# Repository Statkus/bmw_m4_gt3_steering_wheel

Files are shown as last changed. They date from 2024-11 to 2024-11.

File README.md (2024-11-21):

# BMW M4 GT3 steering wheel

This project is a rough replica of the BMW M4 GT3 wheel, entirely printed in 3D with plastic filament.

## Bill of materials

- PLA or any other filament that you like
- screws:
  - 4 x DIN 912 M2 10mm
  - 1 x DIN 912 M2.5 10mm
  - 28 x DIN 912 M3 6mm
  - 6 x DIN 912 M3 16mm
  - 4 x DIN 912 M3 25mm
  - 6 x DIN 912 M5 55mm
  - 8 x DIN 912 M6 22mm
- nuts:
  - 4 x M2
  - 1 x M2.5
  - 10 x M3
  - 6 x M5
  - 8 x M6
- 28 x M3 inserts OD 5mm length 5mm
- 4 x 12x3mm magnets
- tennis handle grip or similar material for the handles
- 1 x WeAct Black Pill V3.0 (https://stm32-base.org/boards/STM32F401CEU6-WeAct-Black-Pill-V3.0) or any STM32F411CEU6 based board with same form factor
- 12 x pins from deutsch connectors 0460-202-20141
- 1 x 12 pins JST PH male connector
- 1 x 12 pins JST PH female connector
- 5 x EC11 encoders with 15mm plum handle with or without push buttons
- 14 x B3F-4055 tactile switches
- 14 x 10mm caps for B3F-4055 tactile switchs
- 2 x DM1-01P-30-3 switches
- wires to link everything

## Source code

### Usage

STM32CubeMX is used to generate STM32 library source files.

Source code can be build with the command:
```
make all
```

And you can flash the program with:
```
make flash
```

STM32CubeMX generates file in DOS format, to convert files to UNIX format use:
```
make format
```

### Fanatec SPI protocol

The SPI protocol used between the fanatec wheel and wheel base as already been retro engineered. Reference of this protocol can be found on the following GitHub repositories:
- https://github.com/Alexbox364/F_Interface_AL
- https://github.com/darknao/btClubSportWheel
- https://github.com/lshachar/Arduino_Fanatec_Wheel

The pinout of the QR pins can already be found on those repositories.

## 3D files

3D_files/Pin_holder_FINAL.stl and 3D_files/Pin_locker_FINAL.stl have been designed by Alexbox364 and are available on Thingiverse: https://www.thingiverse.com/thing:6271297.

The other parts are designed with FreeCAD.

## TODO

- Add clutch paddles

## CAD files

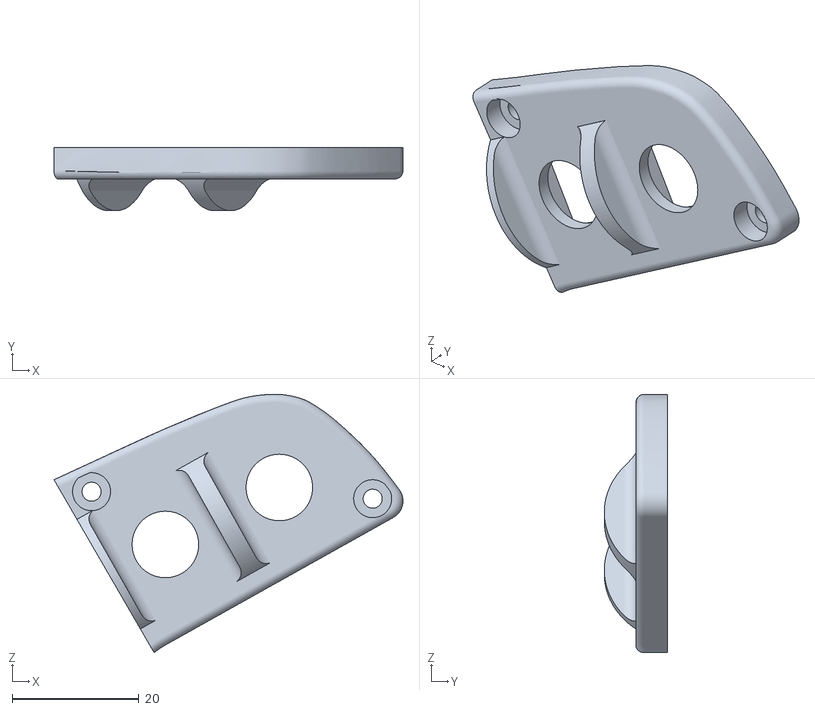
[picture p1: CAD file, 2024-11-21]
3D_files/wheel_tip_front_right.stl
55.1 x 10.0 x 40.8

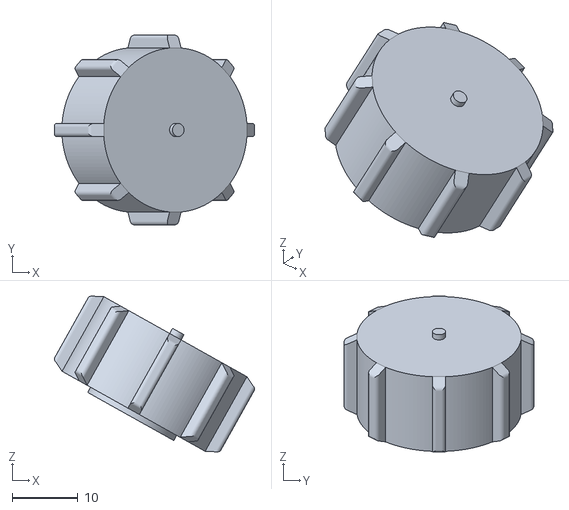
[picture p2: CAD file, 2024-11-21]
3D_files/handle_encoder_cap.stl
30.4 x 28.9 x 23.7

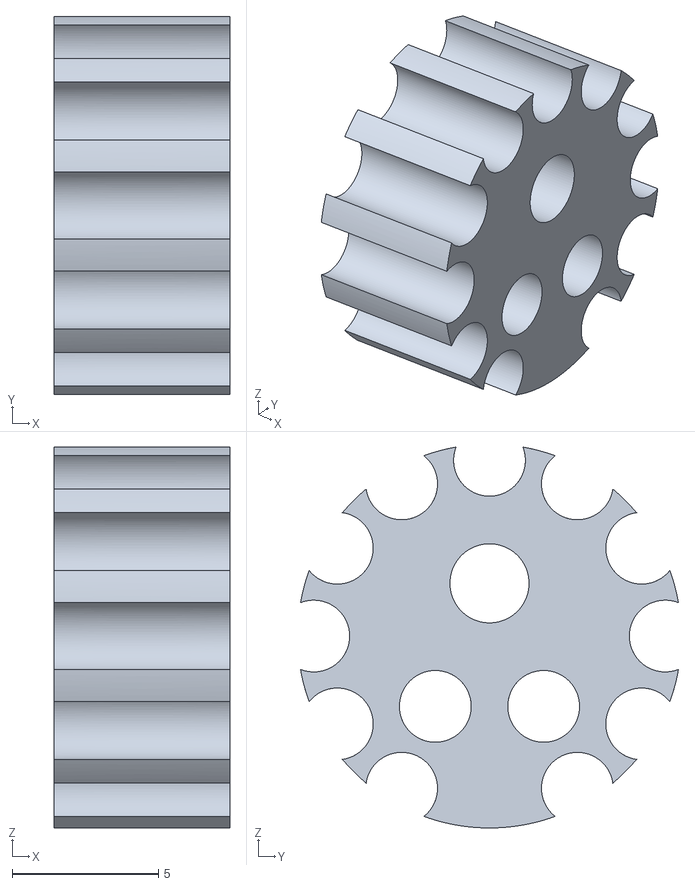
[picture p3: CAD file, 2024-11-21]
3D_files/Pin_locker_FINAL.stl
6.00 x 12.9 x 13.0

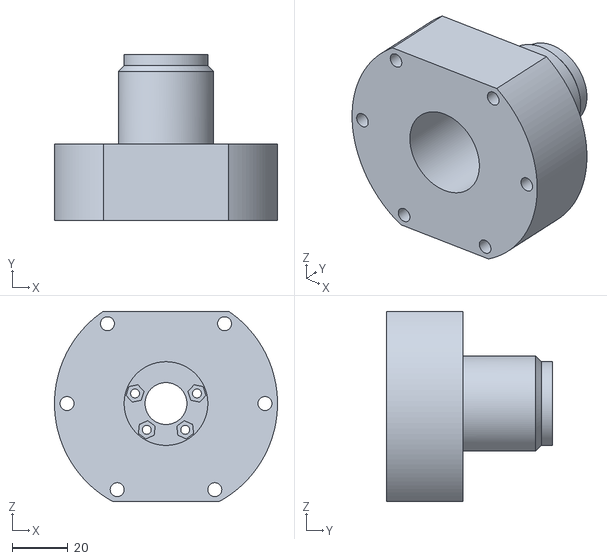
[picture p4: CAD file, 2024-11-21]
3D_files/QR_adapter.stl
80.0 x 59.5 x 68.3

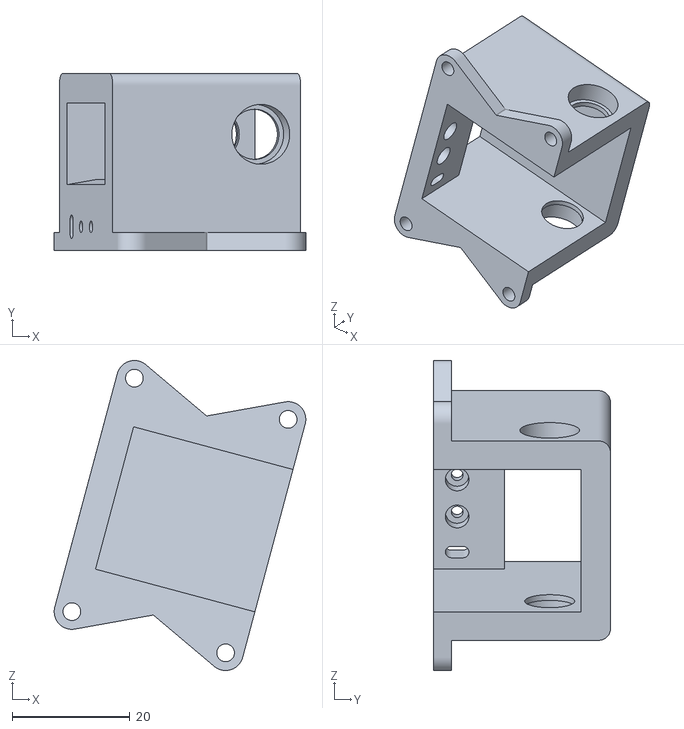
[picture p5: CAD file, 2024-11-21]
3D_files/shifter_core.stl
42.7 x 30.0 x 52.6

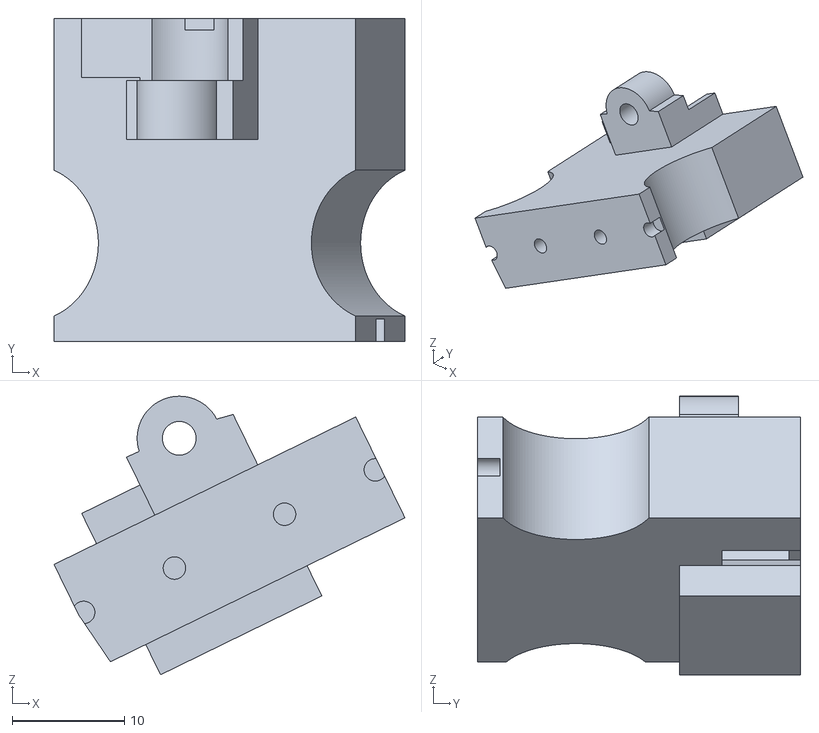
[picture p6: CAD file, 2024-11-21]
3D_files/wheel_tip_internal_right.stl
31.3 x 28.8 x 24.8

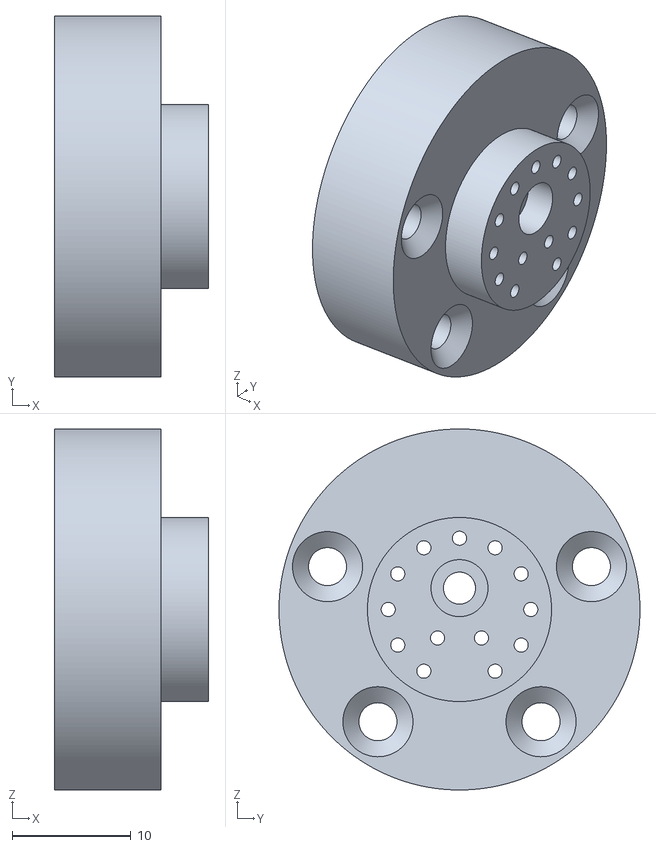
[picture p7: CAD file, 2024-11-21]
3D_files/Pin_holder_FINAL.stl
13.0 x 30.4 x 30.4

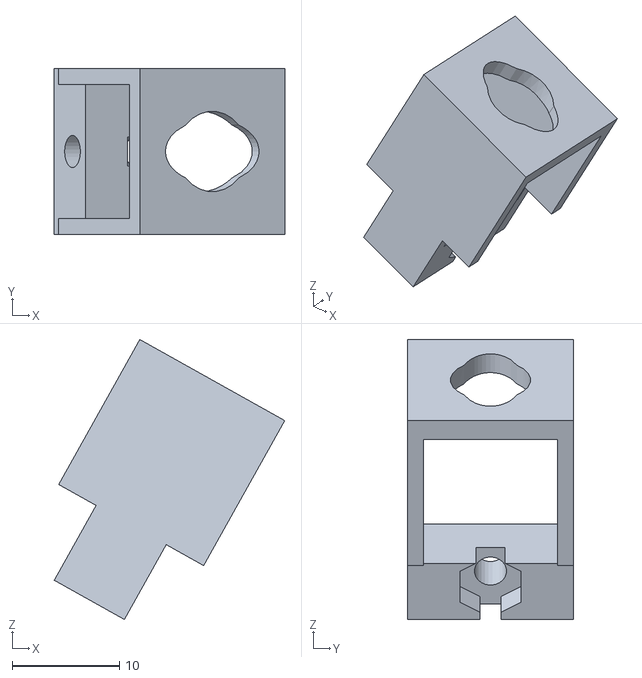
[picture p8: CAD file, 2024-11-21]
3D_files/handle_encoder.stl
21.5 x 15.5 x 26.1

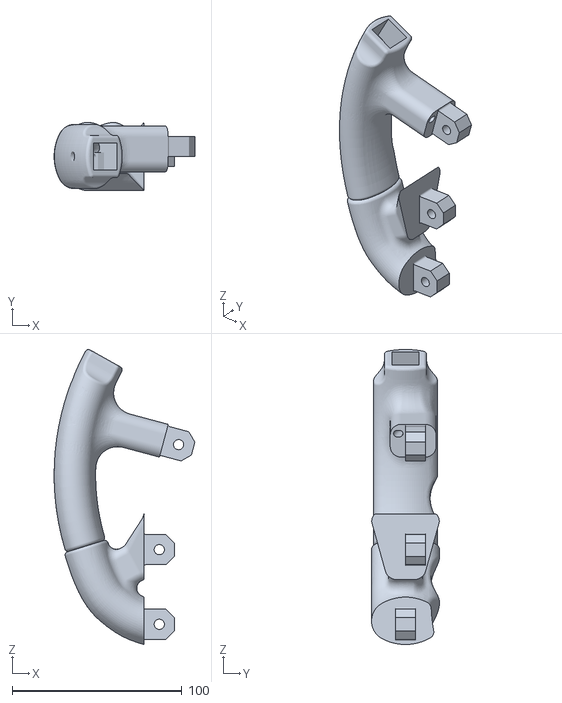
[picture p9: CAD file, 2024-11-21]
3D_files/handle_left.stl
83.0 x 40.0 x 173.9

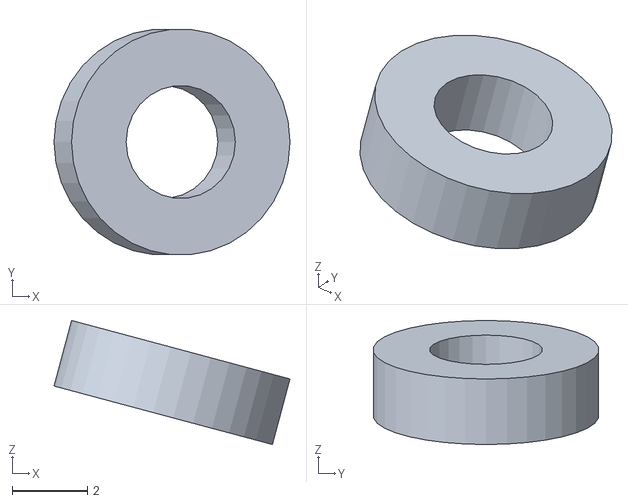
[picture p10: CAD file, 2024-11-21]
3D_files/shifter_bearing_spacer.stl
6.26 x 5.97 x 3.29

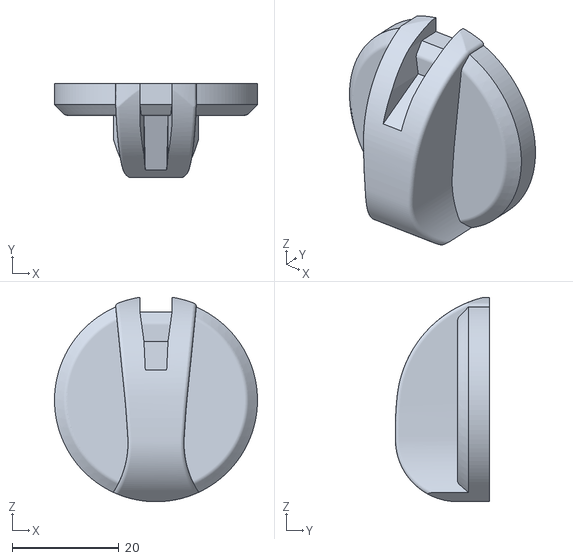
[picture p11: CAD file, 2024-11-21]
3D_files/core_encoder_cap.stl
38.0 x 17.7 x 38.3

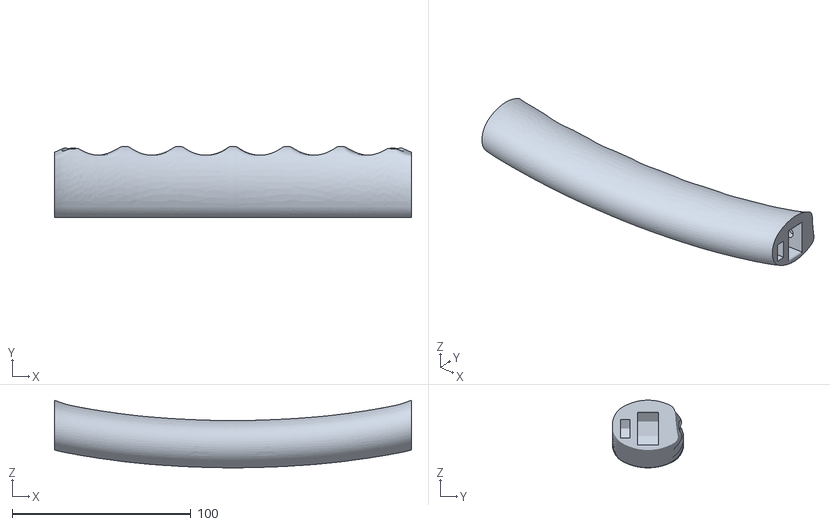
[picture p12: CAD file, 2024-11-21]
3D_files/bottom.stl
200.0 x 40.0 x 37.9

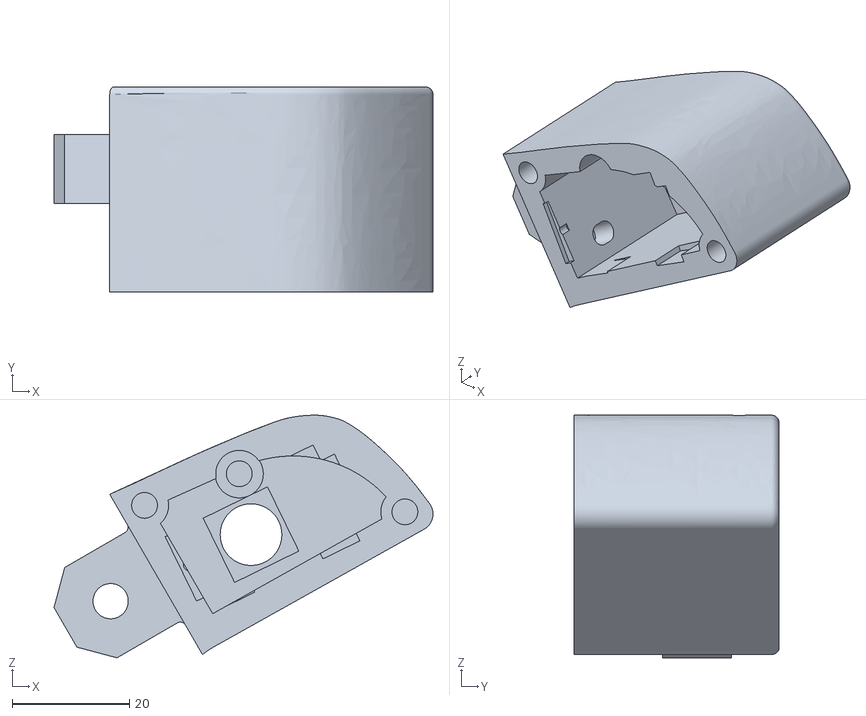
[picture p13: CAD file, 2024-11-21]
3D_files/wheel_tip_back_right.stl
64.6 x 35.0 x 41.4

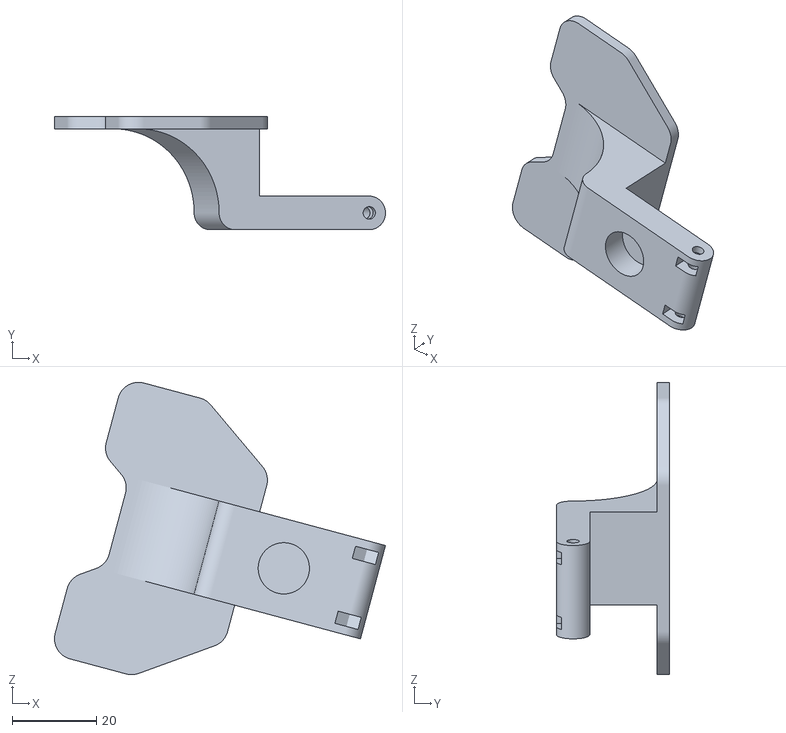
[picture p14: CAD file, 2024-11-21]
3D_files/shifter_paddle.stl
78.8 x 27.0 x 69.6

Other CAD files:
3D_files/handle_right.stl

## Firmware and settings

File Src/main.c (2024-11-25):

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
/* Includes ------------------------------------------------------------------*/
#include "main.h"

/* USER CODE BEGIN Includes */

#include <stdio.h>
#include <string.h>

#include "fanatec.h"

/* USER CODE END Includes */

ADC_HandleTypeDef hadc1;
DMA_HandleTypeDef hdma_adc1;

SPI_HandleTypeDef hspi1;
DMA_HandleTypeDef hdma_spi1_tx;

TIM_HandleTypeDef htim1;

UART_HandleTypeDef huart1;

/* USER CODE BEGIN PV */

struct fanatec_data_out_t fanatec_data_out;

char received_data;

/* USER CODE END PV */

void SystemClock_Config(void);
static void MX_GPIO_Init(void);
static void MX_DMA_Init(void);
static void MX_SPI1_Init(void);
static void MX_USART1_UART_Init(void);
static void MX_ADC1_Init(void);
static void MX_TIM1_Init(void);
/* USER CODE BEGIN PFP */

int _write(int fd, char* ptr, int len);

/* USER CODE END PFP */

/**
  * @brief  The application entry point.
  * @retval int
  */
int main(void)
{

  /* MCU Configuration--------------------------------------------------------*/

  /* Reset of all peripherals, Initializes the Flash interface and the Systick. */
  HAL_Init();

  /* Configure the system clock */
  SystemClock_Config();

  /* Initialize all configured peripherals */
  MX_GPIO_Init();
  MX_DMA_Init();
  MX_SPI1_Init();
  MX_USART1_UART_Init();
  MX_ADC1_Init();
  MX_TIM1_Init();
  /* USER CODE BEGIN 2 */

  memset(fanatec_data_out.raw, 0, sizeof (fanatec_data_out.raw));

  fanatec_data_out.header = 0xA5;
  fanatec_data_out.id     = 0x04; // ID for universal HUB
  fanatec_data_out.fwvers = 0x13; // firmware version for universal HUB
  fanatec_data_out.crc    = Compute_CRC(fanatec_data_out.raw, sizeof(fanatec_data_out.raw) - 1);

  printf("Start main loop\n");

  /* USER CODE END 2 */

  /* Infinite loop */
  /* USER CODE BEGIN WHILE */
  while (1)
  {
    if (HAL_UART_Receive(&huart1, (uint8_t *)&received_data, 1, HAL_MAX_DELAY) == HAL_OK)
    {
      printf("Received: %c\n", received_data);
    }

    HAL_GPIO_TogglePin(LED_GPIO_Port, LED_Pin);

    /* USER CODE END WHILE */

    /* USER CODE BEGIN 3 */
  }
  /* USER CODE END 3 */
}

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
/* USER CODE BEGIN 4 */

void SPI1_CS_High_IRQ_Handler(void)
{
  switch (received_data)
  {
    case 'a':
      fanatec_data_out.buttons[0] = 0x01;
      break;

    case 'b':
      fanatec_data_out.buttons[0] = 0x02;
      break;

    case 'c':
      fanatec_data_out.buttons[0] = 0x04;
      break;

    case 'd':
      fanatec_data_out.buttons[0] = 0x08;
      break;

    case 'e':
      fanatec_data_out.buttons[0] = 0x10;
      break;

    case 'f':
      fanatec_data_out.buttons[0] = 0x20;
      break;

    case 'g':
      fanatec_data_out.buttons[0] = 0x40;
      break;

    case 'h':
      fanatec_data_out.buttons[0] = 0x80;
      break;

    case 'i':
      fanatec_data_out.buttons[1] = 0x01;
      break;

    case 'j':
      fanatec_data_out.buttons[1] = 0x02;
      break;

    case 'k':
      fanatec_data_out.buttons[1] = 0x04;
      break;

    case 'l':
      fanatec_data_out.buttons[1] = 0x08;
      break;

    case 'm':
      fanatec_data_out.buttons[1] = 0x10;
      break;

    case 'n':
      fanatec_data_out.buttons[1] = 0x20;
      break;

    case 'o':
      fanatec_data_out.buttons[1] = 0x40;
      break;

    case 'p':
      fanatec_data_out.buttons[1] = 0x80;
      break;

    case 'q':
      fanatec_data_out.buttons[2] = 0x01;
      break;

    case 'r':
      fanatec_data_out.buttons[2] = 0x02;
      break;

    case 's':
      fanatec_data_out.buttons[2] = 0x04;
      break;

    case 't':
      fanatec_data_out.buttons[2] = 0x08;
      break;

    case 'u':
      fanatec_data_out.buttons[2] = 0x10;
      break;

    case 'v':
      fanatec_data_out.buttons[2] = 0x20;
      break;

    case 'w':
      fanatec_data_out.buttons[2] = 0x40;
      break;

    case 'x':
      fanatec_data_out.buttons[2] = 0x80;
      break;

    case 'y':
      fanatec_data_out.encoder = 1;
      break;

    case 'z':
      fanatec_data_out.encoder = -1;
      break;

    case 'A':
      fanatec_data_out.btnHub[0] = 0x01;
      break;

    case 'B':
      fanatec_data_out.btnHub[0] = 0x02;
      break;

    case 'C':
      fanatec_data_out.btnHub[0] = 0x04;
      break;

    case 'D':
      fanatec_data_out.btnHub[0] = 0x08;
      break;

    case 'E':
      fanatec_data_out.btnHub[0] = 0x10;
      break;

    case 'F':
      fanatec_data_out.btnHub[0] = 0x20;
      break;

    case 'G':
      fanatec_data_out.btnHub[0] = 0x40;
      break;

    case 'H':
      fanatec_data_out.btnHub[0] = 0x80;
      break;

    case 'I':
      fanatec_data_out.btnHub[1] = 0x01;
      break;

    case 'J':
      fanatec_data_out.btnHub[1] = 0x02;
      break;

    case 'K':
      fanatec_data_out.btnHub[1] = 0x04;
      break;

    case 'L':
      fanatec_data_out.btnHub[1] = 0x08;
      break;

    case 'M':
      fanatec_data_out.btnHub[1] = 0x10;
      break;

    case 'N':
      fanatec_data_out.btnHub[1] = 0x20;
      break;

    case 'O':
      fanatec_data_out.btnHub[1] = 0x40;
      break;

    case 'P':
      fanatec_data_out.btnHub[1] = 0x80;
      break;

    case 'Q':
      fanatec_data_out.btnPS[0] = 0x01;
      break;

    case 'R':
      fanatec_data_out.btnPS[0] = 0x02;
      break;

    case 'S':
      fanatec_data_out.btnPS[0] = 0x04;
      break;

    case 'T':
      fanatec_data_out.btnPS[0] = 0x08;
      break;

    case 'U':
      fanatec_data_out.btnPS[0] = 0x10;
      break;

    case 'V':
      fanatec_data_out.btnPS[0] = 0x20;
      break;

    case 'W':
      fanatec_data_out.btnPS[0] = 0x40;
      break;

    case 'X':
      fanatec_data_out.btnPS[0] = 0x80;
      break;

    case 'Y':
      fanatec_data_out.btnPS[1] = 0x01;
      break;

    case 'Z':
      fanatec_data_out.btnPS[1] = 0x02;
      break;

    case '0':
      fanatec_data_out.btnPS[1] = 0x04;
      break;

    case '1':
      fanatec_data_out.btnPS[1] = 0x08;
      break;

    case '2':
      fanatec_data_out.btnPS[1] = 0x10;
      break;

    case '3':
      fanatec_data_out.btnPS[1] = 0x20;
      break;

    case '4':
      fanatec_data_out.btnPS[1] = 0x40;
      break;

    case '5':
      fanatec_data_out.btnPS[1] = 0x80;
      break;

    case '6':
      fanatec_data_out.axisX = 127;
      break;

    case '7':
      fanatec_data_out.axisY = 127;
      break;

    default:
      fanatec_data_out.buttons[0] = 0;
      fanatec_data_out.buttons[1] = 0;
      fanatec_data_out.buttons[2] = 0;
      fanatec_data_out.encoder = 0;
      fanatec_data_out.btnHub[0] = 0;
      fanatec_data_out.btnHub[1] = 0;
      fanatec_data_out.btnPS[0] = 0;
      fanatec_data_out.btnPS[1] = 0;
      fanatec_data_out.axisX = -128;
      fanatec_data_out.axisY = -128;
  }

  fanatec_data_out.crc = Compute_CRC(fanatec_data_out.raw, sizeof(fanatec_data_out.raw) - 1);

  if (HAL_SPI_Transmit_DMA(&hspi1, fanatec_data_out.raw, sizeof(fanatec_data_out.raw)) != HAL_OK)
  {
    Error_Handler();
  }
}

int _write(int fd, char* ptr, int len)
{
    HAL_UART_Transmit(&huart1, (uint8_t *)ptr, len, HAL_MAX_DELAY);
    return len;
}

/* USER CODE END 4 */
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


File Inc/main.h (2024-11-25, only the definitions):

#define LED_Pin GPIO_PIN_13
#define LED_GPIO_Port GPIOC
#define DPAD_ENCODER_A_Pin GPIO_PIN_14
#define DPAD_ENCODER_A_GPIO_Port GPIOC
#define DPAD_ENCODER_B_Pin GPIO_PIN_15
#define DPAD_ENCODER_B_GPIO_Port GPIOC
#define ADC_BUTTONS_RIGHT_Pin GPIO_PIN_0
#define ADC_BUTTONS_RIGHT_GPIO_Port GPIOA
#define ADC_BUTTONS_LEFT_Pin GPIO_PIN_1
#define ADC_BUTTONS_LEFT_GPIO_Port GPIOA
#define SHIFTER_PADDLE_RIGHT_Pin GPIO_PIN_2
#define SHIFTER_PADDLE_RIGHT_GPIO_Port GPIOA
#define SHIFTER_PADDLE_LEFT_Pin GPIO_PIN_3
#define SHIFTER_PADDLE_LEFT_GPIO_Port GPIOA
#define SPI1_CS_Pin GPIO_PIN_4
#define SPI1_CS_GPIO_Port GPIOA
#define SPI1_CS_EXTI_IRQn EXTI4_IRQn
#define ENCODER_1_A_Pin GPIO_PIN_0
#define ENCODER_1_A_GPIO_Port GPIOB
#define ENCODER_1_B_Pin GPIO_PIN_1
#define ENCODER_1_B_GPIO_Port GPIOB
#define ENCODER_2_A_Pin GPIO_PIN_2
#define ENCODER_2_A_GPIO_Port GPIOB
#define ENCODER_2_B_Pin GPIO_PIN_10
#define ENCODER_2_B_GPIO_Port GPIOB
#define DPAD_UP_Pin GPIO_PIN_12
#define DPAD_UP_GPIO_Port GPIOB
#define DPAD_DOWN_Pin GPIO_PIN_13
#define DPAD_DOWN_GPIO_Port GPIOB
#define DPAD_RIGHT_Pin GPIO_PIN_14
#define DPAD_RIGHT_GPIO_Port GPIOB
#define DPAD_LEFT_Pin GPIO_PIN_15
#define DPAD_LEFT_GPIO_Port GPIOB
#define DPAD_BUTTON_Pin GPIO_PIN_8
#define DPAD_BUTTON_GPIO_Port GPIOA
#define BACK_BUTTON_RIGHT_Pin GPIO_PIN_11
#define BACK_BUTTON_RIGHT_GPIO_Port GPIOA
#define BACK_BUTTON_LEFT_Pin GPIO_PIN_12
#define BACK_BUTTON_LEFT_GPIO_Port GPIOA
#define ENCODER_3_A_Pin GPIO_PIN_3
#define ENCODER_3_A_GPIO_Port GPIOB
#define ENCODER_3_B_Pin GPIO_PIN_4
#define ENCODER_3_B_GPIO_Port GPIOB
#define ENCODER_4_A_Pin GPIO_PIN_5
#define ENCODER_4_A_GPIO_Port GPIOB
#define ENCODER_4_B_Pin GPIO_PIN_6
#define ENCODER_4_B_GPIO_Port GPIOB
#define ENCODER_5_A_Pin GPIO_PIN_7
#define ENCODER_5_A_GPIO_Port GPIOB
#define ENCODER_5_B_Pin GPIO_PIN_8
#define ENCODER_5_B_GPIO_Port GPIOB

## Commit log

2024-11-21 [3D] First version of the 3D steering wheel
2024-11-21 [3D] Add steering wheel STL files
    [QR_adapter.stl, bottom.stl, core_encoder_cap.stl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]
2024-11-21 [3D] Add external STL files for QR pins
    [Pin_holder_FINAL.stl, Pin_locker_FINAL.stl]
2024-11-25 [DEV] Add STM32CubeMX project
2024-11-25 [BUILD] Add openocd config file for STM32F411

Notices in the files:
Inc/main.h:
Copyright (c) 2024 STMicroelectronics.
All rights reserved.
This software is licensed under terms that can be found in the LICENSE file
